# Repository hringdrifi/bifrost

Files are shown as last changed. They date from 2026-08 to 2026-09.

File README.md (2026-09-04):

# Bifrǫst

Bifrǫst is a split-keyboard design project by [hringdrifi](https://github.com/hringdrifi).

It is a wireless keyboard design based on the MDBT50Q module, which uses the Nordic nRF52840 SoC.

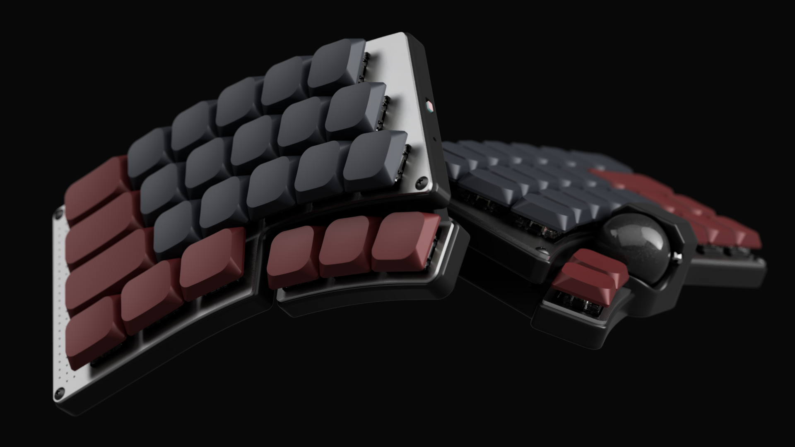
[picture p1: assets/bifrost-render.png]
Bifrǫst split keyboard render


## Project status

This keyboard is currently under active design. It is not yet a validated or production-ready design.

The case CAD files and PCB design files are published here. The keyboard firmware is maintained in the [zmk-config-bifrost repository](https://github.com/hringdrifi/zmk-config-bifrost).

## Available files

- [`case/`](case/README.md) — STEP files for the cases and switch plates
- [`pcb/`](pcb/) — KiCad sources for the five PCBs
- [`docs/manufacturing.md`](docs/manufacturing.md) — manufacturing reference ([日本語](docs/manufacturing.ja.md))
- [Firmware](https://github.com/hringdrifi/zmk-config-bifrost) — ZMK configuration and firmware source

## License

The design data in `case/` and `pcb/` is licensed under the [CERN Open Hardware Licence Version 2 - Permissive (CERN-OHL-P-2.0)](LICENSE).

This license permits use, modification, manufacture, and sale of the design data and products made from it. Modified design data does not need to be published, but applicable notices must be retained and modifications must be documented. The design data and any resulting products are provided without warranty.

The CERN-OHL-P-2.0 license applies to the contents of `case/` and `pcb/`. Firmware is licensed under the [MIT License](https://spdx.org/licenses/MIT.html).

## Disclaimer

Verify dimensions, clearances, compatibility, manufacturability, and safety for your own build before making any parts. Use of these files is at your own risk.

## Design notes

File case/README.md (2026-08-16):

# Bifrǫst case

3D CAD files for the Bifrǫst split-keyboard case. All files are in STEP (ISO 10303-214) format and can be viewed, modified, and manufactured with compatible CAD/CAM software.

## Files

| File | Description |
| --- | --- |
| `bifrost_left_case.step` | Left-hand case |
| `bifrost_right_case.step` | Right-hand case |
| `bifrost_trackball_case.step` | Trackball case |
| `bifrost_switch_knob.step` | Knob for the case-mounted power slide switch |
| `bifrost_left_plate.step` | Left-hand main switch plate |
| `bifrost_right_plate.step` | Right-hand main switch plate |
| `bifrost_left_thumb_plate.step` | Left-hand thumb-cluster switch plate |
| `bifrost_right_thumb_plate.step` | Right-hand thumb-cluster switch plate |

## Project status

These files are design work in progress. They have not been validated for manufacturing, fit, strength, safety, or compatibility with any particular PCB, component, or fabrication process.

Before manufacturing, verify the dimensions and clearances against the parts and process you intend to use.

## License

The STEP files in this directory are provided under the [CERN-OHL-P-2.0](../LICENSE). You may use, copy, modify, manufacture, and sell designs and products based on these files. They are provided without warranty.

See [NOTICE.md](NOTICE.md) for copyright and licensing notices.

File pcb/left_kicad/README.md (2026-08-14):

# Bifrǫst left KiCad design

KiCad source files for the left half of Bifrǫst.

## Status

This is an **incomplete and unverified work in progress**. Do not order boards or rely on this design without independently reviewing the schematic, layout, footprints, mechanical fit, and electrical connections.

The project was initially created from a Smiðr export, then received substantial additional modifications. It is no longer an unmodified Smiðr export.

## Contents

| Design | Purpose |
| --- | --- |
| `bifrost_left.kicad_pro` / `.kicad_sch` / `.kicad_pcb` | Left main PCB |
| `bifrost_left_plate.kicad_pro` / `.kicad_pcb` | Left main switch plate |
| `bifrost_left_thumb.kicad_pro` / `.kicad_sch` / `.kicad_pcb` | Left thumb-cluster PCB |
| `bifrost_left_thumb_plate.kicad_pro` / `.kicad_pcb` | Left thumb-cluster switch plate |
| `smidr.pretty/` | Project footprint library |
| `local.kicad_sym` | Project symbol library |

## Electrical design note

The switch design uses **direct GPIO connections**. Each switch is connected directly between its assigned GPIO net and GND; **there is no diode connected to each switch**.

## Libraries

`fp-lib-table` and `sym-lib-table` configure the project libraries. Keep `smidr.pretty/` and `local.kicad_sym` with this project when opening it in KiCad.

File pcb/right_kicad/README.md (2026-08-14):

# Bifrǫst right KiCad design

KiCad source files for the right half of Bifrǫst.

## Status

This is an **incomplete and unverified work in progress**. Do not order boards or rely on this design without independently reviewing the schematic, layout, footprints, mechanical fit, and electrical connections.

The project was initially created from a Smiðr export, then received substantial additional modifications. It is no longer an unmodified Smiðr export.

## Contents

| Design | Purpose |
| --- | --- |
| `bifrost_right.kicad_pro` / `.kicad_sch` / `.kicad_pcb` | Right main PCB |
| `bifrost_right_plate.kicad_pro` / `.kicad_pcb` | Right main switch plate |
| `bifrost_right_thumb.kicad_pro` / `.kicad_sch` / `.kicad_pcb` | Right thumb-cluster PCB |
| `bifrost_right_thumb_plate.kicad_pro` / `.kicad_pcb` | Right thumb-cluster switch plate |
| `bifrost_right_trackball.kicad_pro` / `.kicad_sch` / `.kicad_pcb` | Trackball PCB |
| `smidr.pretty/` | Project footprint library |
| `local.kicad_sym` | Project symbol library |

## Electrical design note

The switch design uses **direct GPIO connections**. Each switch is connected directly between its assigned GPIO net and GND; **there is no diode connected to each switch**.

## Libraries

`fp-lib-table` and `sym-lib-table` configure the project libraries. Keep `smidr.pretty/` and `local.kicad_sym` with this project when opening it in KiCad.

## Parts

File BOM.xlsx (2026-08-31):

left |  |  |  |  | right |  |  |  |  | leftthumb |  |  |  |  | rightthumb |  |  |  |  | righttrackball
Designator | Footprint | Quantity | Value | LCSC Part # | Designator | Footprint | Quantity | Value | LCSC Part # | Designator | Footprint | Quantity | Value | LCSC Part # | Designator | Footprint | Quantity | Value | LCSC Part # | Designator | Footprint | Quantity | Value | LCSC Part #
C1, C2, C3, C9 | 402 | 4 | 10u | C15525 | C1, C2, C3, C9 | 402 | 4 | 10u | C15525 | C1, C2 | 402 | 2 | 100n | C1525 | C1, C2, C3 | 402 | 3 | 100n | C1525 | C1, C3 | 402 | 2 | 10n | C15195
C4, C5 | 402 | 2 | 12pF | C1547 | C4, C5 | 402 | 2 | 12pF | C1547 | D1, D2 | 2020 | 2 | WS2812B-2020 | C55109522 | D1, D2, D3 | 2020 | 3 | WS2812B-2020 | C55109522 | C2, C5, C6 | 402 | 3 | 100n | C1525
C6, C8 | 402 | 2 | 100n | C1525 | C6, C8 | 402 | 2 | 100n | C1525 | H1, H2 |  | 2 | MountingHole | C2928170 | H1, H2 |  | 2 | MountingHole | C2928170 | C4 | 402 | 1 | 10u | C15525
C7 | 402 | 1 | 4.7u | C23733 | C7 | 402 | 1 | 4.7u | C23733 |  |  |  |  |  |  |  |  |  |  | C7 | 402 | 1 | 1u | C52923
CHG1 | 603 | 1 | Red | C19189741 | CHG1 | 603 | 1 | Red | C19189741 |  |  |  |  |  |  |  |  |  |  | C9 | 402 | 1 | 4.7uF/10V | C23733
D1 | D_SOD-323 | 1 | BSD3C051V | C151996 | D1 | D_SOD-323 | 1 | BSD3C051V | C151996 |  |  |  |  |  |  |  |  |  |  | R10 | 402 | 1 | 10k | C25744
D2 | D_SOD-323 | 1 | 1N5819WS | C191023 | D2 | D_SOD-323 | 1 | 1N5819WS | C191023 |  |  |  |  |  |  |  |  |  |  | U1 |  | 1 | PMW3610
D3 | LED_Smidr_RGB_1209 | 1 | E6C1209RGBC3UDA | C375572 |  |  |  |  |  |  |  |  |  |  |  |  |  |  |  | U2 |  | 1 | MCP1700T-1802E/TT | C150796
F1 | 1206 | 1 | PTC 1A hold | C883131 | F1 | 1206 | 1 | PTC 1A hold | C883131
J1 | USB_C_Receptacle_HRO_TYPE-C-31-M-12 | 1 | HRO_TYPE-C-31-M-12 | C165948 | J1 | USB_C_Receptacle_HRO_TYPE-C-31-M-12 | 1 | HRO_TYPE-C-31-M-12 | C165948
L1 | 603 | 1 | 10uH | C86083 | L1 | 603 | 1 | 10uH | C86083
L2, L3 | 402 | 2 | BLM15PX121SN1D | C88970 | L2, L3 | 402 | 2 | BLM15PX121SN1D | C88970
Q1, Q3 | SOT-23 | 2 | AO3401A | C15127 | Q1, Q3 | SOT-23 | 2 | AO3401A | C15127
Q2 | SOT-23 | 1 | 2N7002 | C8545 | Q2 | SOT-23 | 1 | 2N7002 | C8545
R1, R2 | 402 | 2 | 27 | C25100 | R1, R2 | 402 | 2 | 27 | C25100
R10, R11 | 402 | 2 | 4.7k | C25900
R12 | 402 | 1 | 1k | C11702
R13, R9 | 402 | 2 | 10k | C25744 | R10, R9 | 402 | 2 | 10k | C25744
R3 | 402 | 1 | 1.5k | C25867 | R3 | 402 | 1 | 1.5k | C25867
R4 | 402 | 1 | 100k | C25741 | R4 | 402 | 1 | 100k | C25741
R5, R6 | 402 | 2 | 5.1k | C25905 | R5, R6 | 402 | 2 | 5.1k | C25905
R7 | 402 | 1 | 3.3k | C25890 | R7 | 402 | 1 | 3.3k | C25890
R8 | 402 | 1 | 100 | C25076 | R8 | 402 | 1 | 100 | C25076
S1 | SW_SPDT_Shouhan_MSK12C02 | 1 | MSK12C02-HB | C431541 | S1 | SW_SPDT_Shouhan_MSK12C02 | 1 | MSK12C02-HB | C431541
T1 | SW_SMD_2P-TS24CA | 1 | TS24CA | C393942 | T1 | SW_SMD_2P-TS24CA | 1 | TS24CA | C393942
TP1 | TestPoint_THTPad_D1.0mm_Drill0.5mm | 1 | SWDIO |  | TP1 | TestPoint_THTPad_D1.0mm_Drill0.5mm | 1 | SWDIO
TP2 | TestPoint_THTPad_D1.0mm_Drill0.5mm | 1 | SWDCLK |  | TP2 | TestPoint_THTPad_D1.0mm_Drill0.5mm | 1 | SWDCLK
U1 | Raytac_MDBT50Q | 1 | MDBT50Q-1MV2 | C5118826 | U1 | Raytac_MDBT50Q | 1 | MDBT50Q-1MV2 | C5118826
U2 | SOT-23-6 | 1 | TP4057 | C12044 | U2 | SOT-23-6 | 1 | TP4057 | C12044
U3 | SOT-23-6 | 1 | SRV05-4 | C7420376 | U3 | SOT-23-6 | 1 | SRV05-4 | C7420376
X1 | Crystal_SMD_MicroCrystal_CC7V-T1A-2Pin_3.2x1.5mm | 1 | 32.768kHz | C32346 | X1 | Crystal_SMD_MicroCrystal_CC7V-T1A-2Pin_3.2x1.5mm | 1 | 32.768kHz | C32346

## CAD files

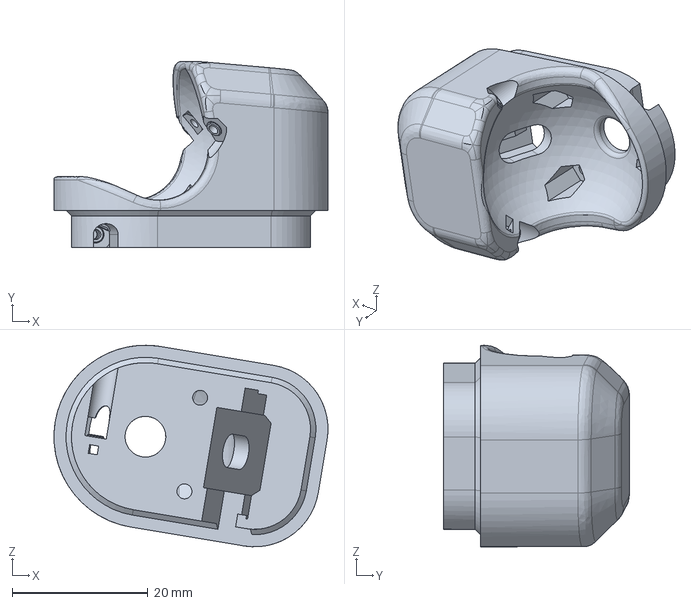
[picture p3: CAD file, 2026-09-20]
case/bifrost_trackball_case.step
40.4 x 27.5 x 29.7 mm

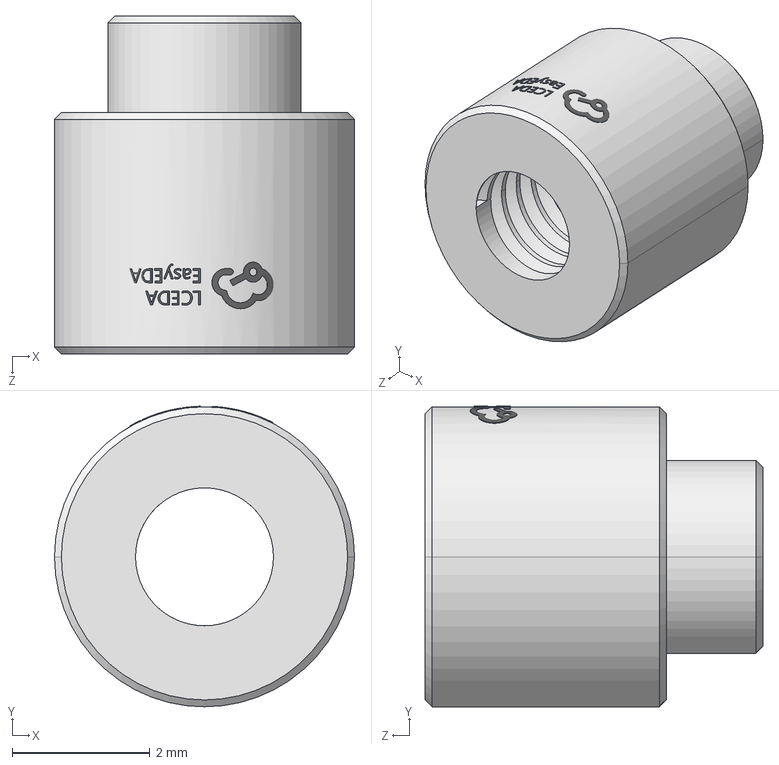
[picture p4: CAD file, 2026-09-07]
pcb/left_kicad/3dmodels/SMD-1_BD4.4-D2.8.step
4.35 x 4.36 x 4.90 mm

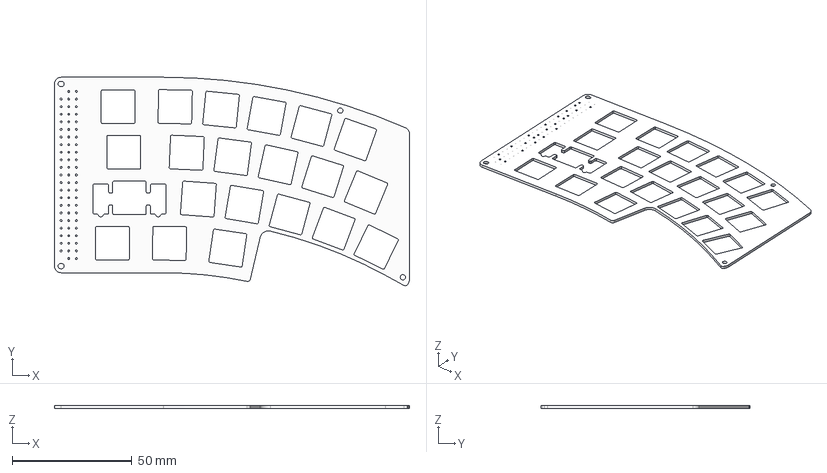
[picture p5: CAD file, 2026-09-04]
case/bifrost_left_plate.step
148.4 x 87.2 x 1.20 mm

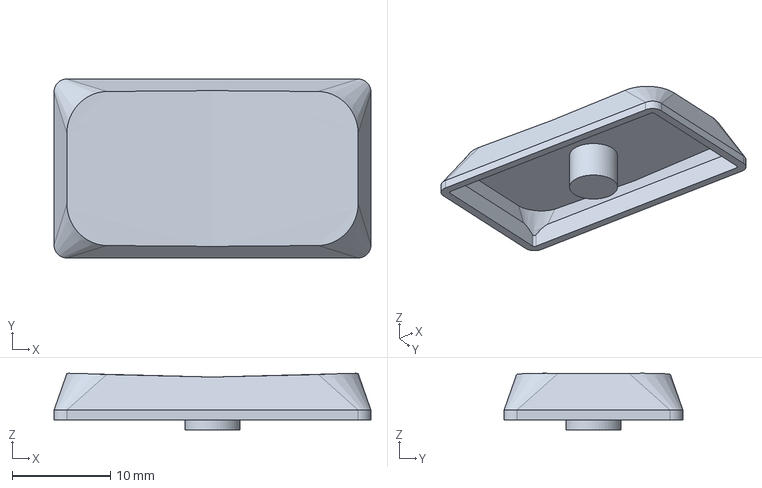
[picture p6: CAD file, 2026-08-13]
pcb/left_kicad/3dmodels/Low Profile Keycap 1.75U.step
32.3 x 18.2 x 5.76 mm

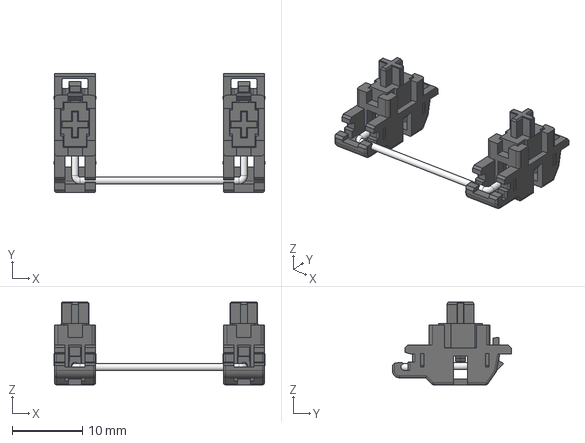
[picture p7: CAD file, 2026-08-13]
pcb/right_kicad/3dmodels/Gateron Low Profile Stabilizer 2U.step
30.0 x 17.0 x 11.8 mm

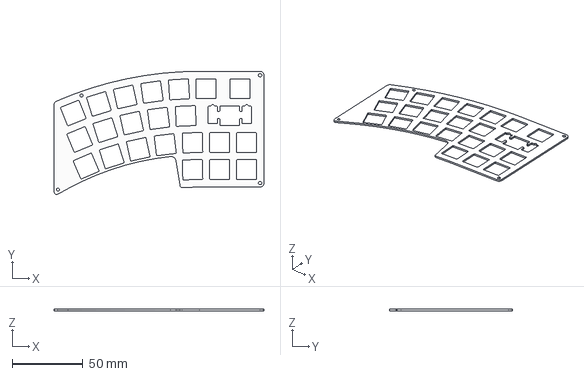
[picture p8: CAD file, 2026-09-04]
case/bifrost_right_plate.step
148.4 x 87.2 x 1.20 mm

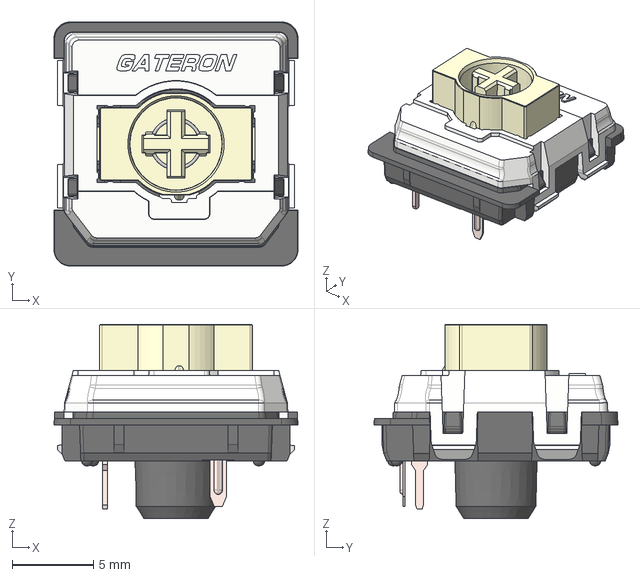
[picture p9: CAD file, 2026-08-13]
pcb/left_kicad/3dmodels/Gateron Low Profile Switch V2.step
15.0 x 15.0 x 11.9 mm

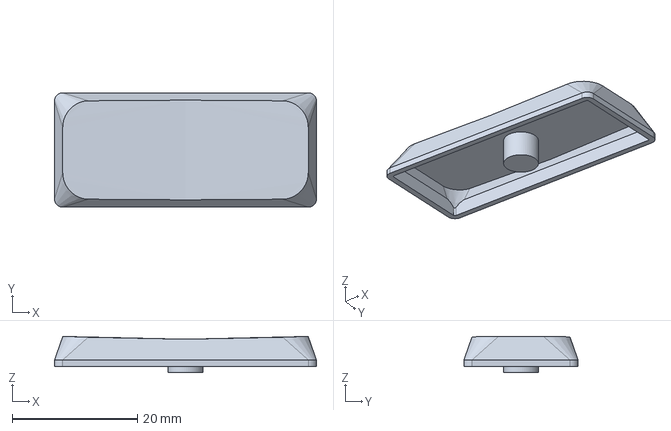
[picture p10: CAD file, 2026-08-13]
pcb/right_kicad/3dmodels/Low Profile Keycap 2.25U.step
41.8 x 18.2 x 5.76 mm

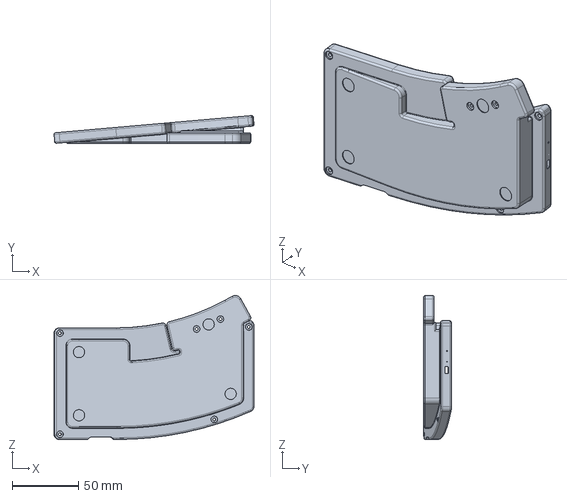
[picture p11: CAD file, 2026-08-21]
case/bifrost_left_case.step
150.7 x 21.0 x 108.6 mm

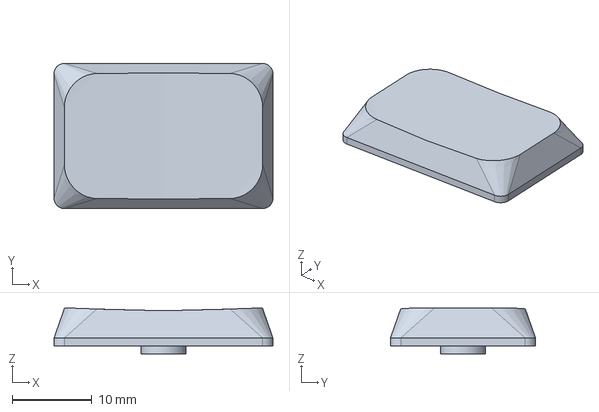
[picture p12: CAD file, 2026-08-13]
pcb/left_kicad/3dmodels/Low Profile Keycap 1.5U.step
27.5 x 18.2 x 5.75 mm

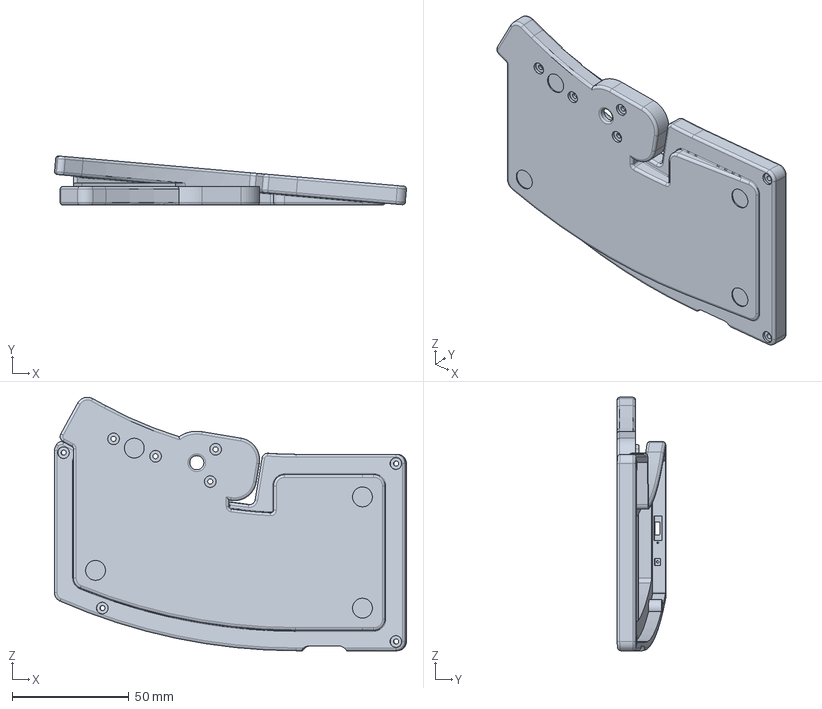
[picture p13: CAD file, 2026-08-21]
case/bifrost_right_case.step
150.7 x 21.0 x 108.6 mm

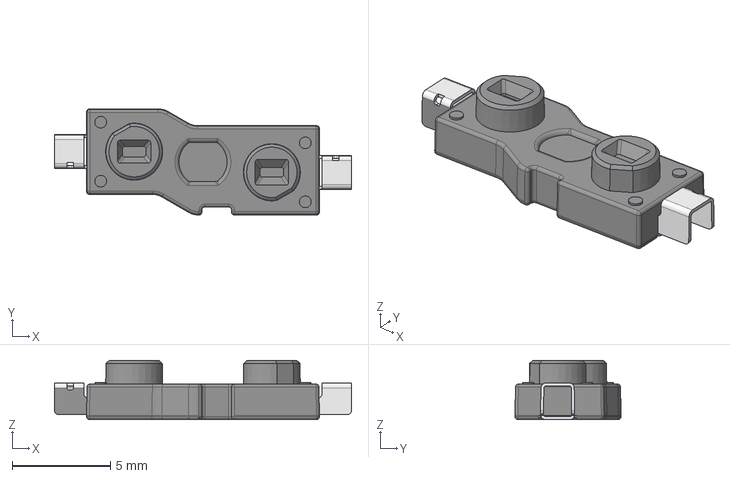
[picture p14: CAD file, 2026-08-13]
pcb/left_kicad/3dmodels/Gateron Low Profile Socket.step
15.1 x 5.39 x 3.00 mm

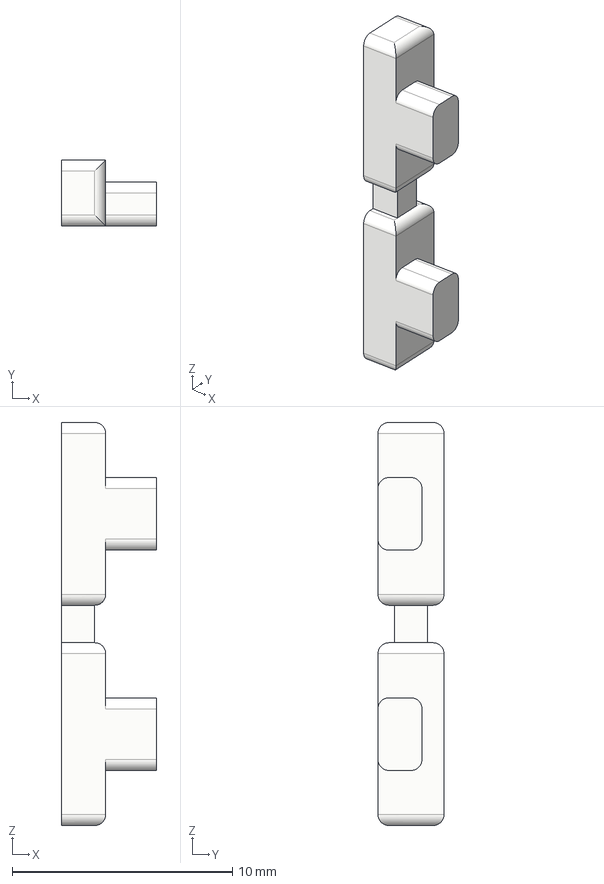
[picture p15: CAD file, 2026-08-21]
case/bifrost_switch_knob.step
4.30 x 3.00 x 18.3 mm

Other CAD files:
case/bifrost_left_thumb_plate.step
case/bifrost_right_thumb_plate.step
pcb/left_kicad/3dmodels/Low Profile Keycap 1.25U.step
pcb/left_kicad/3dmodels/Low Profile Keycap 1U.step
pcb/left_kicad/3dmodels/Low Profile Keycap 2U.step
pcb/right_kicad/3dmodels/Low Profile Keycap 1U.step

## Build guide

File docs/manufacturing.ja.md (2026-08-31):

# 製造資料

この文書は Bifrǫst を製造するための暫定資料です。調達・製造条件を扱い、はんだ付けや組み立て手順は別のビルドガイドで公開します。

> リンク先の在庫、納期、仕様、注文条件は変わる場合があります。注文前に必ず販売元の最新情報を確認してください。価格は掲載しません。

## 製造対象

キーボード 1 台あたり、次の 5 種類の基板を使用します。

1. 左右メイン基板（左）
2. 左右メイン基板（右）
3. トラックボール基板
4. 左親指クラスタ基板
5. 右親指クラスタ基板

ケースおよび 4 種類のプレートは [`case/`](../case/) に、基板設計データは [`pcb/`](../pcb/) にあります。

## 部品

| 部品 | 仕様 | 1 台あたり | 推奨購入先 | 型番 |
| --- | --- | ---: | --- | --- |
| トラスねじ | M2 × 4 mm | 22 本 | [Wilco](https://wilco.jp/) | `FT-0204EB` |
| ねじ | M1.4 × 5 mm | 3 本 | [Wilco](https://wilco.jp/) | `F-1450N-01` |
| アルミ製丸型両雌ねじスペーサー | M2 × 5 mm | 8 本 | [ヒロスギ](https://hirosugi.co.jp/)（[Web ショップ](https://www.hirosugi-net.co.jp/)） | `ARL-2005E` |
| ナット | M2 | 2 個 | [Wilco](https://wilco.jp/) | `FNT-02N` |
| 薄ナット | M1.4 | 3 個 | [Wilco](https://wilco.jp/) | `UNTD-014` |
| ゴム足 | φ7.9 × H2.2 mm | 8 個 | [Amazon](https://www.amazon.co.jp/) | `SJ5302` または `CS-01` |
| スイッチ | Gateron Low Profile ホットスワップ | 49 個 | TBD | `KS-27 Gateron Low Profile` または `KS-33 Gateron Low Profile 2.0` |
| スタビライザー | Gateron Low Profile、プレートマウント | 2 個 | TBD | `KS-57 Gateron Low Profile Plate Mounted Stabilizer` |
| トラックボール球 | 25 mm | 1 個 | TBD | — |
| トラックボール用ベアリング | 内径1.5 × 外径4 × 幅2 mm | 3 個 | TBD | ミネベア `DDL-415ZZ` |
| リチウムポリマー電池 | 1 セル（公称 3.7 V）、保護回路付き、最大寸法：厚み 6 × 幅 35 × 高さ 55 mm | 2 個 | TBD | TBD |
| メイン基板－バッテリー接続ワイヤハーネス | 2 芯、PicoBlade（1.25 mm ピッチ・2 ピン）オス／メスの 75 mm ピグテールを中間で接続 | 2 本 | Molex | `2181110200` + `2181120200` |
| 左メイン基板－左親指クラスタ基板接続ワイヤハーネス | 6 芯、PicoBlade（1.25 mm ピッチ・6 ピン）オス／メスの 75 mm ピグテールを中間で接続 | 1 本 | Molex | `2181110600` + `2181120600` |
| 右メイン基板－右親指クラスタ基板接続ワイヤハーネス | 5 芯、PicoBlade（1.25 mm ピッチ・5 ピン）オス／メスの 75 mm ピグテールを中間で接続 | 1 本 | Molex | `2181110500` + `2181120500` |
| 右メイン基板－トラックボール基板接続ワイヤハーネス | 6 芯、PicoBlade（1.25 mm ピッチ・6 ピン）オス／メスの 75 mm ピグテールを中間で接続 | 1 本 | Molex | `2181110600` + `2181120600` |

> アルミ製プレートに真鍮製のねじを直接接触させ、水分や塩分が介在すると、異種金属接触によってアルミ側の腐食が促進される場合があります。通常の乾燥した室内環境では大きな問題になりませんが、耐食性を優先する場合はステンレス製の締結部品を使用してください。

PicoBlade コネクタは基板上ではなく、各ハーネスの途中に着脱部として設けます。`218111` はオス－ピグテール、`218112` はメス－ピグテールのアセンブリ済みケーブルで、被覆むき線端を各基板へ接続します。各ハーネスは最短の 75 mm 品をオス・メス 1 本ずつ使用します。バッテリー用ハーネスは 2 ピンです。発注前にコネクタ形状、極数、ピン配列を現物および基板データで確認してください。

### リチウムポリマー電池に関する注意・免責

リチウムポリマー電池は、短絡、過充電、物理的な損傷、不適切な充電により発熱、発火、破裂するおそれがあります。本資料は電池、充電器、ハーネス、または完成品の安全性・適合性を保証するものではなく、組み立て、使用、充電、保管、廃棄は製作者・使用者の責任で行ってください。

- 充電は基板上の充電回路を介して行います。バッテリーまたはハーネスへ外部充電器を直接接続しないでください。保護回路付きの 1 セル電池を使用してください。
- 膨張、損傷、異臭、異常な発熱がある電池は使用・充電せず、電池メーカーおよび地域の廃棄ルールに従って処分してください。
- 可燃物の近く、就寝中、または監視できない状態で充電しないでください。極性と配線を確認してから接続してください。

## ケース製造

次の部品を **SLA レジン 3D プリント**で製造します。

| 部品 | ファイル | 1 台あたり |
| --- | --- | ---: |
| 左ケース | `bifrost_left_case.step` | 1 個 |
| 右ケース | `bifrost_right_case.step` | 1 個 |
| トラックボールケース | `bifrost_trackball_case.step` | 1 個 |
| 電源スイッチ用ノブ（2 個一体モデル） | `bifrost_switch_knob.step` | 1 モデル（ノブ 2 個） |

電源スイッチ用ノブは単体では小さすぎて製造できないため、2 個をつないだ 1 つの 3D モデルとして出力します。出力後に 2 個のノブを切り離してください。

- 推奨製造先: [JLC3DP](https://jlc3dp.com/)
- 製法: SLA レジン
- レジンの種類・色・表面仕上げ: **製作者が任意に選択**
- 後加工: **不要**
- ゴム足: 最終組み立て時に 3M `SJ5302` を 8 個取り付けます。

## PCB 製造

- 推奨製造先: [JLCPCB](https://jlcpcb.com/)
- 1 台あたり: **5 種類の基板**

| 基板 | 基板厚 |
| --- | ---: |
| 左メイン基板 | **1.2 mm** |
| 右メイン基板 | **1.2 mm** |
| 左親指クラスタ基板 | **1.2 mm** |
| 右親指クラスタ基板 | **1.2 mm** |
| トラックボール基板 | **1.6 mm** |

### 注文条件 — 未確定

注文前に以下を確定します。

| 項目 | 条件 |
| --- | --- |
| 基板ごとの注文数 | TBD |
| 層数 | 2 層 |
| 銅箔厚 | 1 oz（35 µm）— トラックボール基板は要確認 |
| レジスト色 | 製造者が任意に選択 |
| 表面処理 | TBD |
| 外形・面付け条件 | TBD |
| 電気検査 | TBD |
| 実装サービス | TBD |
| 製造ファイル | 左右メイン基板は下表のGerber ZIP、BOM、部品位置ファイルを使用 |

### 左右メイン基板の製造・実装データ

左メイン基板と右メイン基板は、それぞれ1枚ずつで1台分です。JLCPCB実装では各基板ごとに、Gerber ZIP、BOM CSV、部品位置CSVを同じ組み合わせでアップロードしてください。BOMの `LCSC Part #` はJLCPCB/LCSCの部品番号です。

| 基板 | Gerber ZIP | BOM | 部品位置 |
| --- | --- | --- | --- |
| 左メイン基板 | [`bifrost_left.zip`](../pcb/left_kicad/production/bifrost_left.zip) | [`bom.csv`](../pcb/left_kicad/production/bom.csv) | [`positions.csv`](../pcb/left_kicad/production/positions.csv) |
| 右メイン基板 | [`bifrost_right.zip`](../pcb/right_kicad/production/bifrost_right.zip) | [`bom.csv`](../pcb/right_kicad/production/bom.csv) | [`positions.csv`](../pcb/right_kicad/production/positions.csv) |

現在のBOMにおける要確認部品は次のとおりです。

| 部品 | 指定部品 | JLCPCB/LCSC Part # | 備考 |
| --- | --- | --- | --- |
| J1 | Korean Hroparts `TYPE-C-31-M-12` | `C165948` | 基板の `HRO_TYPE-C-31-M-12` フットプリントに対応するUSB Type-Cレセプタクル |
| L1 | Murata `LQM18FN100M00D` | `C86083` | 10 µH、0603。nRF52840のDC/DC用 |
| F1 | BHFUSE `BSMD1206-100-16V` | `C883131` | 1 A hold PTC |
| D2 | Guangdong Hottech `1N5819WS` | `C191023` | SOD-323ショットキーダイオード |

この表にない実装部品も、必ず上記のBOM CSVに記載された部品番号を使用してください。スイッチ、バッテリー、ハーネスなど、BOM CSVに含まれない部品は別途調達・組み立てします。

## プレート製造

4 種類のスイッチプレートはレーザーカット、またはアルミ基板で製造できます。厚みは **1.2 mm** です。

アルミ基板を使い、アルミ面を上面にする場合は、**プレートのデータを表裏反転して発注**してください。

- 推奨製造先: [JLCPCB](https://jlcpcb.com/)
- 対象ファイル: `bifrost_left_plate.step`、`bifrost_right_plate.step`、`bifrost_left_thumb_plate.step`、`bifrost_right_thumb_plate.step`

## 今後追記する内容

- PCB の詳細な注文条件
- 親指クラスタ・トラックボール基板の実装データと部品購入リンク
- 製造データのリビジョン番号

## 関連資料

- [English version](manufacturing.md)
- はんだ付け、機械組み立て、ファームウェア書き込みは別のビルドガイドで扱います。

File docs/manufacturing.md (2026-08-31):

# Manufacturing reference

This document is a work in progress for manufacturing Bifrǫst. It covers procurement and fabrication requirements; assembly instructions will be published separately in a build guide.

> Availability, lead time, specifications, and ordering conditions at linked suppliers may change. Verify the current product page and specification before ordering. Prices are intentionally not listed here.

## Production scope

One keyboard requires five PCB designs:

1. Left main PCB
2. Right main PCB
3. Trackball PCB
4. Left thumb-cluster PCB
5. Right thumb-cluster PCB

The case and four switch plates are provided as STEP files in [`case/`](../case/). The PCB design sources are in [`pcb/`](../pcb/).

## Parts

| Part | Specification | Qty. per keyboard | Recommended supplier | Part number |
| --- | --- | ---: | --- | --- |
| Truss-head screw | M2 × 4 mm | 22 | [Wilco](https://wilco.jp/) | `FT-0204EB` |
| Screw | M1.4 × 5 mm | 3 | [Wilco](https://wilco.jp/) | `F-1450N-01` |
| Aluminium round female-to-female spacer | M2 × 5 mm | 8 | [Hirosugi](https://hirosugi.co.jp/) ([web shop](https://www.hirosugi-net.co.jp/)) | `ARL-2005E` |
| Nut | M2 | 2 | [Wilco](https://wilco.jp/) | `FNT-02N` |
| Thin nut | M1.4 | 3 | [Wilco](https://wilco.jp/) | `UNTD-014` |
| Bumpon / rubber foot | Ø7.9 × H2.2 mm | 8 | [Amazon](https://www.amazon.co.jp/) | `SJ5302` or `CS-01` |
| Switch | Gateron Low Profile hotswap | 49 | TBD | `KS-27 Gateron Low Profile` or `KS-33 Gateron Low Profile 2.0` |
| Stabilizer | Gateron Low Profile, plate-mounted | 2 | TBD | `KS-57 Gateron Low Profile Plate Mounted Stabilizer` |
| Trackball ball | 25 mm | 1 | TBD | — |
| Trackball bearing | ID1.5 × OD4 × W2 mm | 3 | TBD | Minebea `DDL-415ZZ` |
| Lithium-polymer battery | Single cell (3.7 V nominal), with protection circuit; maximum dimensions: 6 mm thick × 35 mm wide × 55 mm high | 2 | TBD | TBD |
| Main PCB–battery wire harness | Two-conductor; inline connection between 75 mm male and female PicoBlade (1.25 mm pitch, 2 pin) pigtails | 2 | Molex | `2181110200` + `2181120200` |
| Left main PCB–left thumb-cluster PCB wire harness | Six-conductor; inline connection between 75 mm male and female PicoBlade (1.25 mm pitch, 6 pin) pigtails | 1 | Molex | `2181110600` + `2181120600` |
| Right main PCB–right thumb-cluster PCB wire harness | Five-conductor; inline connection between 75 mm male and female PicoBlade (1.25 mm pitch, 5 pin) pigtails | 1 | Molex | `2181110500` + `2181120500` |
| Right main PCB–trackball PCB wire harness | Six-conductor; inline connection between 75 mm male and female PicoBlade (1.25 mm pitch, 6 pin) pigtails | 1 | Molex | `2181110600` + `2181120600` |

> Direct contact between aluminium plates and brass screws can accelerate corrosion of the aluminium if moisture or salt is present. This is not normally significant in a dry indoor environment, but use stainless-steel fasteners where corrosion resistance is a priority.

Place the PicoBlade connector in each harness as an inline disconnect, not on either PCB. `218111` is a male-to-pigtail and `218112` a female-to-pigtail pre-assembled cable; connect their blunt wire ends to the respective PCBs. Each harness uses one 75 mm male and one 75 mm female pigtail, the shortest available length. The battery harnesses use 2-pin connectors. Confirm connector mating, pin count, and pinout against the actual parts and PCB design data before ordering.

### Lithium-polymer battery notice and disclaimer

Lithium-polymer batteries can overheat, catch fire, or rupture if short-circuited, overcharged, physically damaged, or improperly charged. This reference does not warrant the safety or compatibility of any battery, charger, harness, or completed product; builders and users are responsible for assembly, use, charging, storage, and disposal.

- Charge through the on-board charging circuit. Do not connect an external charger directly to the battery or harness; use protected single-cell batteries.
- Do not use or charge batteries that are swollen, damaged, unusually hot, or emitting an odour. Dispose of them according to the battery manufacturer's instructions and local rules.
- Do not charge near combustible materials, while asleep, or while the battery cannot be supervised. Verify polarity and wiring before connecting.

## Case fabrication

Manufacture the following parts by **SLA resin 3D printing**:

| Part | File | Qty. per keyboard |
| --- | --- | ---: |
| Left-hand case | `bifrost_left_case.step` | 1 |
| Right-hand case | `bifrost_right_case.step` | 1 |
| Trackball case | `bifrost_trackball_case.step` | 1 |
| Power-switch knob (two-knob joined model) | `bifrost_switch_knob.step` | 1 model (2 knobs) |

The power-switch knobs are too small to manufacture individually, so the STEP file contains two knobs joined as one 3D-printing model. Separate the two knobs after printing.

- Recommended manufacturer: [JLC3DP](https://jlc3dp.com/)
- Manufacturing process: SLA resin
- Resin type, colour, and surface finish: **at the builder's discretion**
- Post-processing: **not required**
- Rubber feet: apply eight 3M `SJ5302` bump-ons during final assembly.

## PCB fabrication

- Recommended manufacturer: [JLCPCB](https://jlcpcb.com/)
- Required design count: **5 distinct PCBs** per keyboard

| PCB | Board thickness |
| --- | ---: |
| Left main PCB | **1.2 mm** |
| Right main PCB | **1.2 mm** |
| Left thumb-cluster PCB | **1.2 mm** |
| Right thumb-cluster PCB | **1.2 mm** |
| Trackball PCB | **1.6 mm** |

### Order specification — to be confirmed

Fill in the following before placing an order:

| Item | Requirement |
| --- | --- |
| Quantity per design | TBD |
| Layer count | 2 |
| Copper weight | 1 oz (35 µm) — verify for the trackball PCB |
| Solder mask colour | Builder's choice |
| Surface finish | TBD |
| Edge / panel requirements | TBD |
| Electrical test | TBD |
| Assembly service | TBD |
| Manufacturing files | Use the Gerber ZIP, BOM, and pick-and-place files in the table below for the main PCBs |

### Main-PCB fabrication and assembly data

One keyboard requires one left main PCB and one right main PCB. For JLCPCB assembly, upload the matching Gerber ZIP, BOM CSV, and pick-and-place CSV for each PCB. `LCSC Part #` in the BOM is the JLCPCB/LCSC component number.

| PCB | Gerber ZIP | BOM | Pick-and-place |
| --- | --- | --- | --- |
| Left main PCB | [`bifrost_left.zip`](../pcb/left_kicad/production/bifrost_left.zip) | [`bom.csv`](../pcb/left_kicad/production/bom.csv) | [`positions.csv`](../pcb/left_kicad/production/positions.csv) |
| Right main PCB | [`bifrost_right.zip`](../pcb/right_kicad/production/bifrost_right.zip) | [`bom.csv`](../pcb/right_kicad/production/bom.csv) | [`positions.csv`](../pcb/right_kicad/production/positions.csv) |

The following application-specific selections in the current BOM deserve particular attention:

| Reference | Selected part | JLCPCB/LCSC Part # | Note |
| --- | --- | --- | --- |
| J1 | Korean Hroparts `TYPE-C-31-M-12` | `C165948` | USB Type-C receptacle matching the board's `HRO_TYPE-C-31-M-12` footprint |
| L1 | Murata `LQM18FN100M00D` | `C86083` | 10 µH, 0603; nRF52840 DC/DC inductor |
| F1 | BHFUSE `BSMD1206-100-16V` | `C883131` | 1 A hold PTC |
| D2 | Guangdong Hottech `1N5819WS` | `C191023` | SOD-323 Schottky diode |

For all other assembled components, use the exact part number in the linked BOM CSV. Switches, batteries, harnesses, and other items absent from the CSV are sourced and assembled separately.

## Switch plates

The four switch plates may be made by laser cutting or as aluminium-core PCBs. Use **1.2 mm** material.

When ordering an aluminium-core PCB and using the aluminium face as the top surface, **mirror the plate artwork before fabrication**.

- Recommended manufacturer: [JLCPCB](https://jlcpcb.com/)
- Plate files: `bifrost_left_plate.step`, `bifrost_right_plate.step`, `bifrost_left_thumb_plate.step`, and `bifrost_right_thumb_plate.step`

## Still to be specified

- PCB order specifications listed above
- Assembly data and component sourcing links for the thumb-cluster and trackball PCBs
- Manufacturing-export revision identifiers

## Related documents

- [Japanese version](manufacturing.ja.md)
- A separate build guide will cover soldering, mechanical assembly, and firmware flashing.

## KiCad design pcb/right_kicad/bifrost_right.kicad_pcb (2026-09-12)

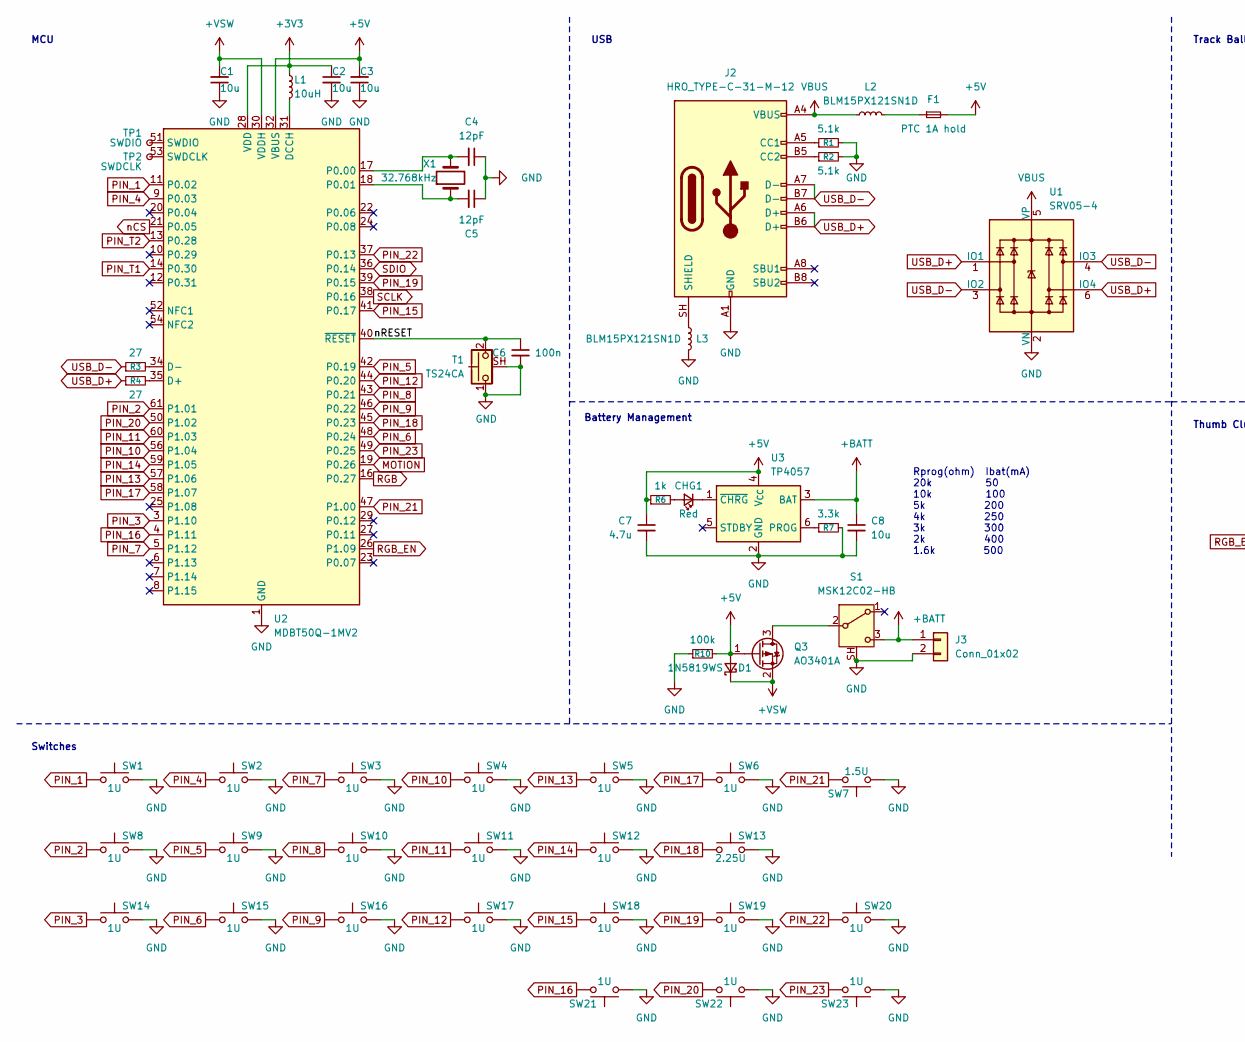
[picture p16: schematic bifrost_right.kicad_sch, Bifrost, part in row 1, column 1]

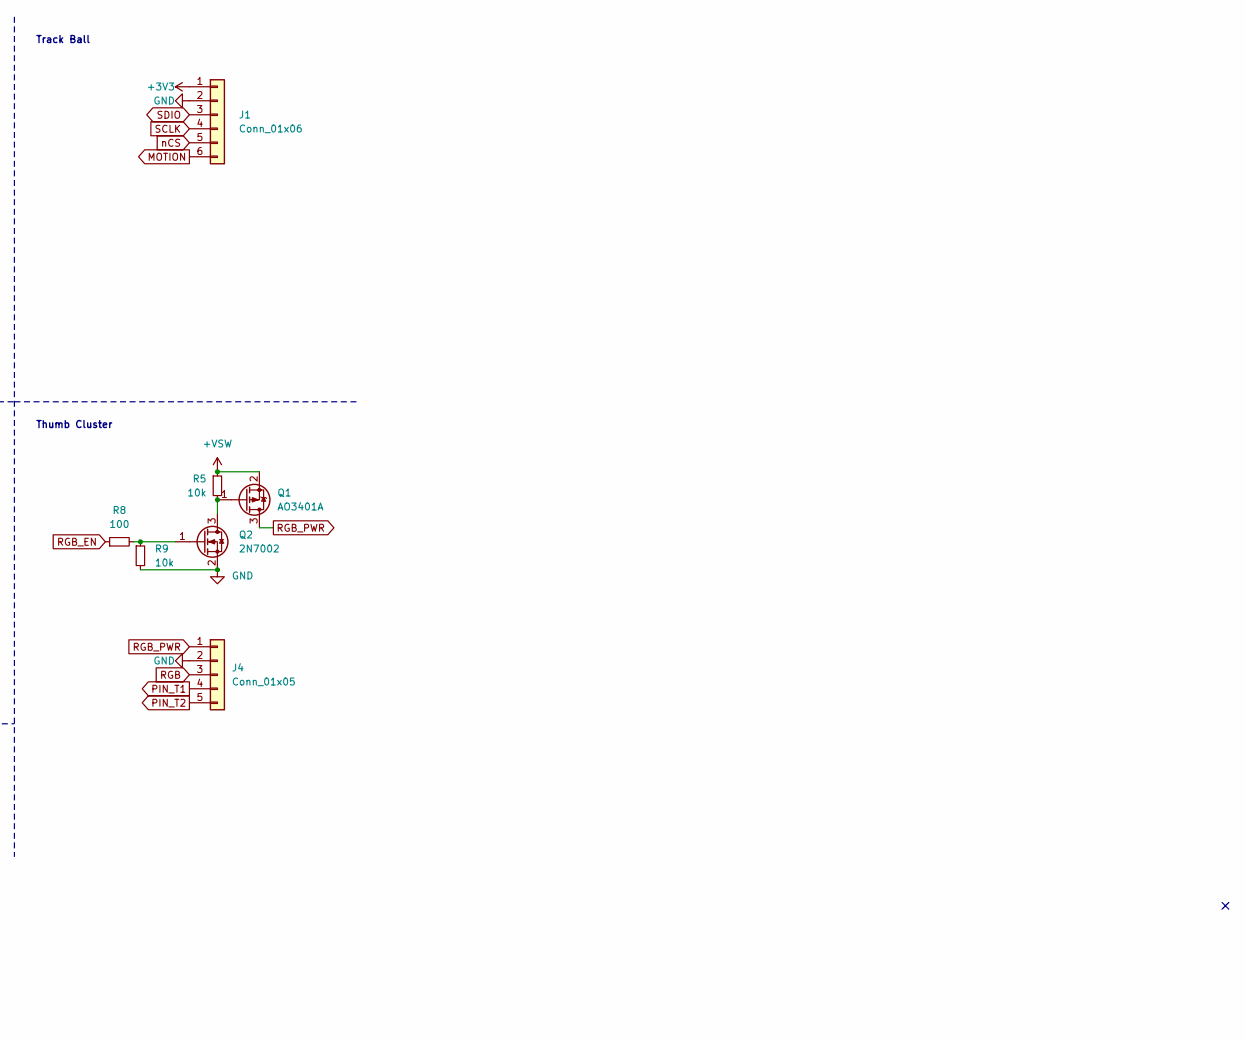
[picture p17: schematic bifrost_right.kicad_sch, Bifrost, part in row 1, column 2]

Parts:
C1, C2, C3, C8: 10u; C_0402_1005Metric; JLCPCB Part # C15525
C4, C5: 12pF; C_0402_1005Metric; JLCPCB Part # C1547
C6: 100n; C_0402_1005Metric; JLCPCB Part # C1525
C7: 4.7u; C_0402_1005Metric; JLCPCB Part # C23733
CHG1: Red; LED_0603_1608Metric; JLCPCB Part # C19189741
D1: 1N5819WS; D_SOD-323; JLCPCB Part # C191023
F1: PTC 1A hold; Fuse_1206_3216Metric; JLCPCB Part # C883131
J1: Conn_01x06; PinHeader_1x06_P1.27mm_Vertical
J2: HRO_TYPE-C-31-M-12; USB_C_Receptacle_HRO_TYPE-C-31-M-12; JLCPCB Part # C165948
J3: Conn_01x02; PinHeader_1x02_P1.27mm_Vertical
J4: Conn_01x05; PinHeader_1x05_P1.27mm_Vertical
L1: 10uH; L_0603_1608Metric; JLCPCB Part # C86083
L2, L3: BLM15PX121SN1D; L_0402_1005Metric; JLCPCB Part # C88970
Q1, Q3: AO3401A; SOT-23; JLCPCB Part # C15127
Q2: 2N7002; SOT-23; JLCPCB Part # C8545
R1, R2: 5.1k; R_0402_1005Metric; JLCPCB Part # C25905
R3, R4: 27; R_0402_1005Metric; JLCPCB Part # C25100
R5, R9: 10k; R_0402_1005Metric; JLCPCB Part # C25744
R6: 1k; R_0402_1005Metric; JLCPCB Part # C11702
R7: 3.3k; R_0402_1005Metric; JLCPCB Part # C25890
R8: 100; R_0402_1005Metric; JLCPCB Part # C25076
R10: 100k; R_0402_1005Metric; JLCPCB Part # C25741
S1: MSK12C02-HB; SW_SPDT_Shouhan_MSK12C02; JLCPCB Part # C431541
SW1, SW2, SW3, SW4, SW5, SW6, SW8, SW9, SW10, SW11, SW12, SW14, SW15, SW16, SW17, SW18, SW19, SW20, SW21, SW22, SW23: 1U; SW_Smidr_Gateron_LP_Hotswap
SW7: 1.5U; SW_Smidr_Gateron_LP_Hotswap
SW13: 2.25U; SW_Smidr_Gateron_LP_Hotswap
T1: TS24CA; SW_SMD_2P-TS24CA; JLCPCB Part # C393942
TP1: SWDIO; TestPoint_THTPad_D1.0mm_Drill0.5mm
TP2: SWDCLK; TestPoint_THTPad_D1.0mm_Drill0.5mm
U1: SRV05-4; SOT-23-6; JLCPCB Part # C7420376
U2: MDBT50Q-1MV2; Raytac_MDBT50Q; JLCPCB Part # C5118826
U3: TP4057; SOT-23-6; JLCPCB Part # C12044
X1: 32.768kHz; Crystal_SMD_MicroCrystal_CC7V-T1A-2Pin_3.2x1.5mm; JLCPCB Part # C479190

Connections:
+3V3: C2.1, J1.1, L1.1, U2.28 (VDD)
+5V: C3.2, C7.1, D1.2 (A), F1.2, Q3.1 (G), R6.1, R10.2, U2.32 (VBUS), U3.4 (V_{CC})
+BATT: C8.1, J3.1, S1.3 (C), U3.3 (BAT)
+VSW: C1.2, D1.1 (K), Q1.2 (S), Q3.2 (S), R5.1, U2.30 (VDDH)
/nRESET: C6.1, T1.2, U2.40 (~RESET)
GND: C1.1, C2.2, C3.1, C4.1, C5.1, C6.2, C7.2, C8.2, J1.2, J2.A1 (GND), J2.A12 (GND), J2.B1 (GND), J2.B12 (GND), J3.2, J4.2, L3.2, Q2.2 (S), R1.2, R2.2, R7.2, R9.2, R10.1, S1.SH, SW1.2, SW2.2, SW3.2, SW4.2, SW5.2, SW6.2, SW7.1, SW8.2, SW9.2, SW10.2, SW11.2, SW12.2, SW13.2, SW14.2, SW15.2, SW16.2, SW17.2, SW18.2, SW19.2, SW20.2, SW21.1, SW22.1, SW23.1, T1.1, T1.SH (B), U1.2 (VN), U2.1 (GND), U2.2 (GND), U2.15 (GND), U2.33 (GND), U2.55 (GND), U3.2 (GND)
MOTION: J1.6, U2.19 (P0.26)
unnamed: CHG1.2 (A), R6.2
unnamed: CHG1.1 (K), U3.1 (~CHRG)
unnamed: F1.1, L2.2
unnamed: J2.A5 (CC1), R1.1
unnamed: J2.B5 (CC2), R2.1
unnamed: J2.SH (SHIELD), L3.1
unnamed: Q1.1 (G), Q2.3 (D), R5.2
unnamed: Q2.1 (G), R8.2, R9.1
unnamed: Q3.3 (D), S1.2 (B)
unnamed: R4.2, U2.35 (D+)
unnamed: R3.2, U2.34 (D-)
unnamed: L1.2, U2.31 (DCCH)
unnamed: C4.2, U2.17 (P0.00), X1.2
unnamed: C5.2, U2.18 (P0.01), X1.1
unnamed: TP2.1 (1_1), U2.53 (SWDCLK)
unnamed: TP1.1 (1_1), U2.51 (SWDIO)
unnamed: R7.1, U3.6 (PROG)
PIN_1: SW1.1, U2.11 (P0.02)
PIN_2: SW8.1, U2.61 (P1.01)
PIN_3: SW14.1, U2.3 (P1.10)
PIN_4: SW2.1, U2.9 (P0.03)
PIN_5: SW9.1, U2.42 (P0.19)
PIN_6: SW15.1, U2.48 (P0.24)
PIN_7: SW3.1, U2.5 (P1.12)
PIN_8: SW10.1, U2.43 (P0.21)
PIN_9: SW16.1, U2.46 (P0.22)
PIN_10: SW4.1, U2.56 (P1.04)
PIN_11: SW11.1, U2.60 (P1.03)
PIN_12: SW17.1, U2.44 (P0.20)
PIN_13: SW5.1, U2.57 (P1.06)
PIN_14: SW12.1, U2.59 (P1.05)
PIN_15: SW18.1, U2.41 (P0.17)
PIN_16: SW21.2, U2.4 (P1.11)
PIN_17: SW6.1, U2.58 (P1.07)
PIN_18: SW13.1, U2.45 (P0.23)
PIN_19: SW19.1, U2.39 (P0.15)
PIN_20: SW22.2, U2.50 (P1.02)
PIN_21: SW7.2, U2.47 (P1.00)
PIN_22: SW20.1, U2.37 (P0.13)
PIN_23: SW23.2, U2.49 (P0.25)
PIN_T1: J4.4, U2.14 (P0.30)
PIN_T2: J4.5, U2.13 (P0.28)
RGB: J4.3, U2.16 (P0.27)
RGB_EN: R8.1, U2.26 (P1.09)
RGB_PWR: J4.1, Q1.3 (D)
SCLK: J1.4, U2.38 (P0.16)
SDIO: J1.3, U2.36 (P0.14)
USB_D+: J2.A6 (D+), J2.B6 (D+), R4.1, U1.1 (IO1), U1.6 (IO4)
USB_D-: J2.A7 (D-), J2.B7 (D-), R3.1, U1.3 (IO2), U1.4 (IO3)
VBUS: J2.A4 (VBUS), J2.A9 (VBUS), J2.B4 (VBUS), J2.B9 (VBUS), L2.1, U1.5 (VP)
nCS: J1.5, U2.21 (P0.05)

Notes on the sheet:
Thumb Cluster
MCU
Battery Management
Track Ball
USB
Rprog(ohm) Ibat(mA) 20k 50 10k 100 5k 200 4k 250 3k 300 2k 400 1.6k 500
Switches

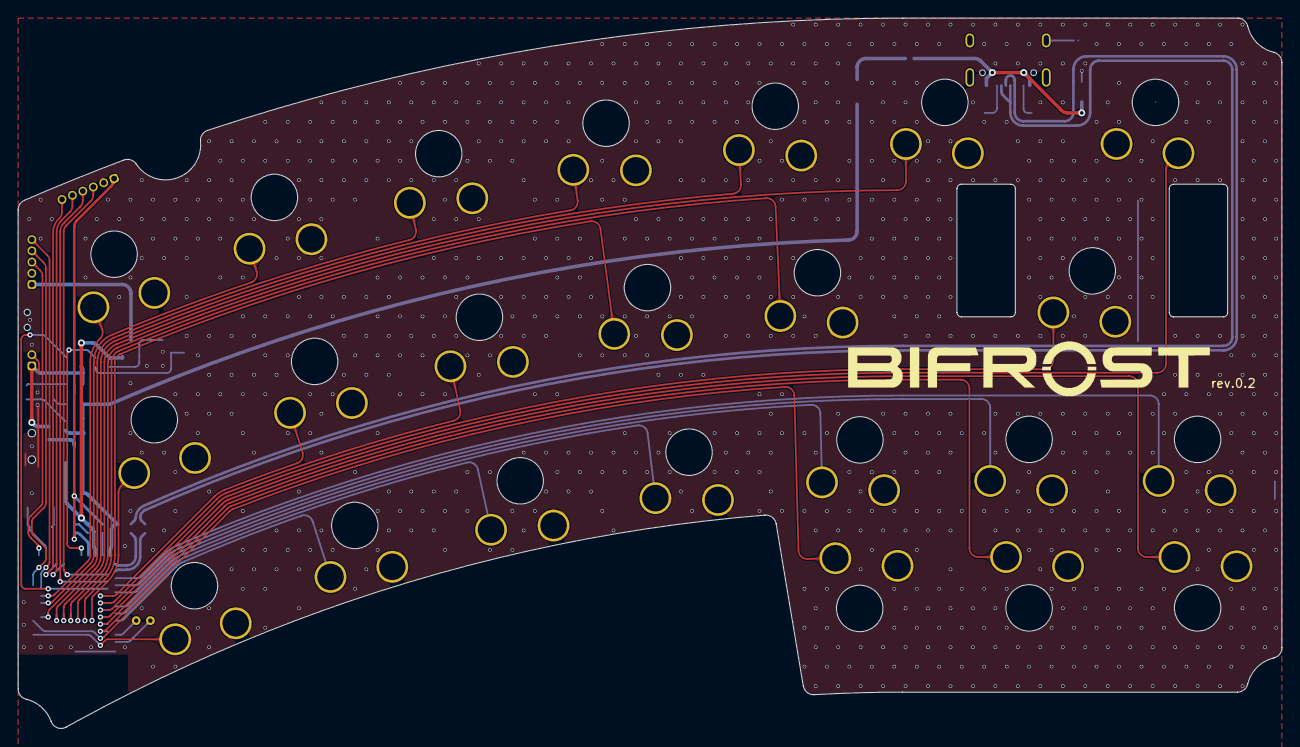
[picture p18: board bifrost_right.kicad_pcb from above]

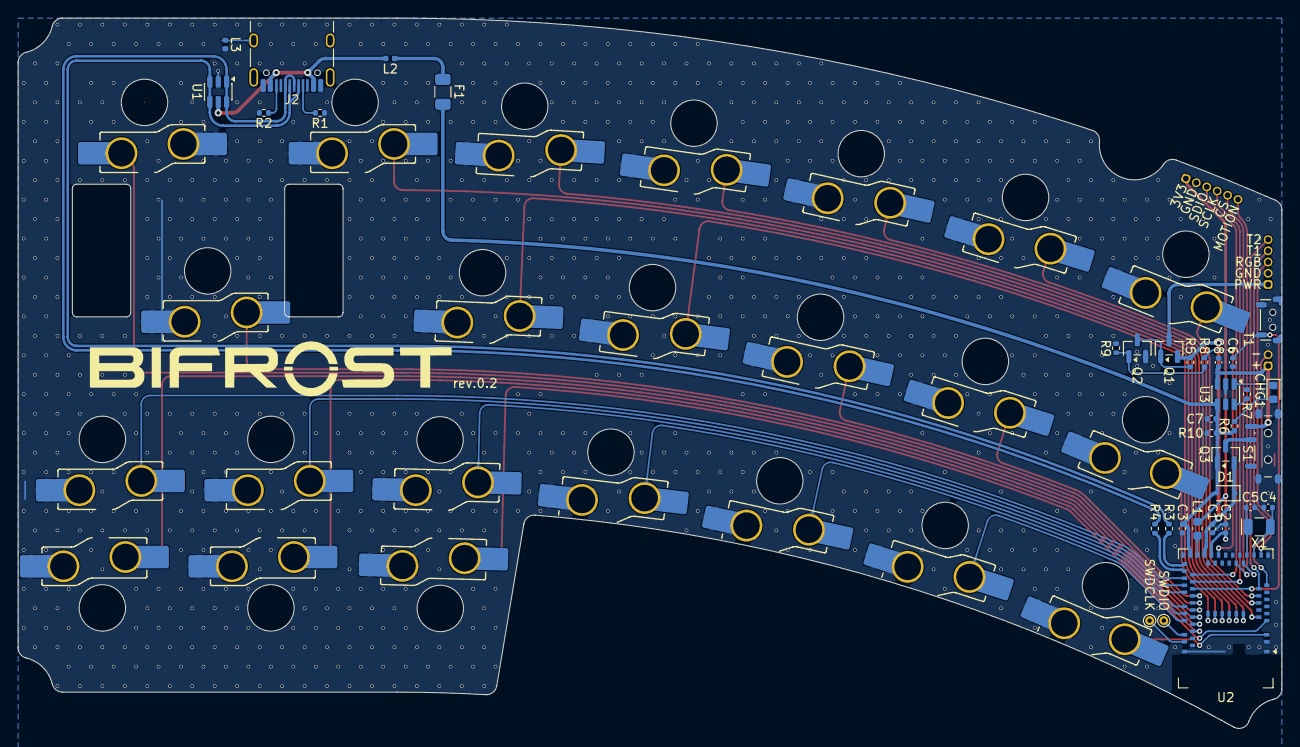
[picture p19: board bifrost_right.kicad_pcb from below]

Board: 2 copper layers, 142.9 x 80.3 mm, 62 parts (62 on the bottom side), 58 nets.

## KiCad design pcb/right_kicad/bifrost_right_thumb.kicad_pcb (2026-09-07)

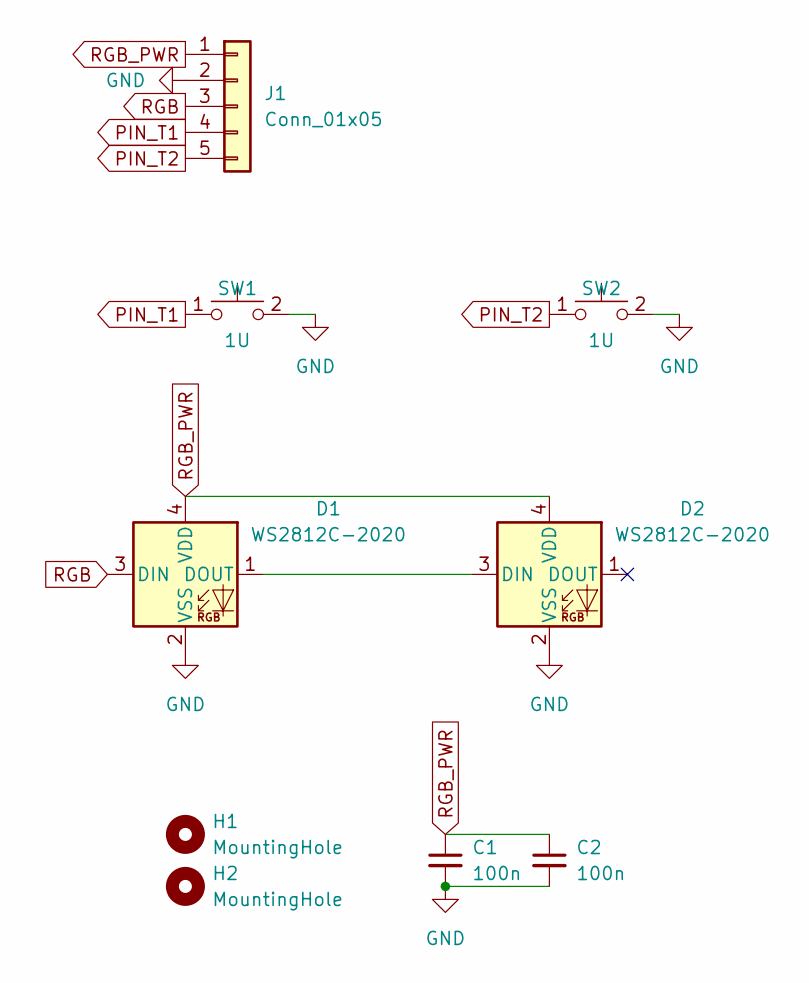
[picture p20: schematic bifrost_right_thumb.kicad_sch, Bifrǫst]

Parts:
C1, C2: 100n; C_0402_1005Metric; JLCPCB Part # C1525
D1, D2: WS2812C-2020; LED_WS2812B-2020_PLCC4_2.0x2.0mm; JLCPCB Part # C55109522
H1, H2: MountingHole; SMD-1_BD4.4-D2.8; JLCPCB Part # C2928179
J1: Conn_01x05; PinHeader_1x05_P1.27mm_Vertical
SW1, SW2: 1U; SW_Smidr_Gateron_LP_Hotswap

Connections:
GND: C1.2, C2.2, D1.2 (VSS), D2.2 (VSS), J1.2, SW1.2, SW2.2
unnamed: D1.1 (DOUT), D2.3 (DIN)
PIN_T1: J1.4, SW1.1
PIN_T2: J1.5, SW2.1
RGB: D1.3 (DIN), J1.3
RGB_PWR: C1.1, C2.1, D1.4 (VDD), D2.4 (VDD), J1.1

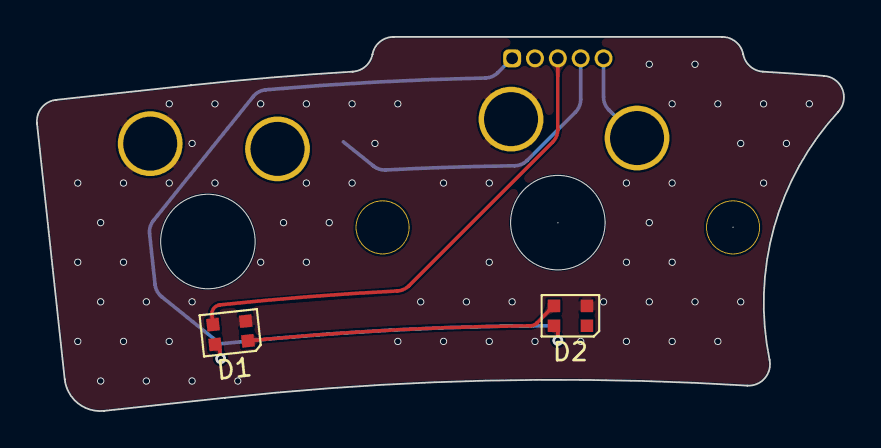
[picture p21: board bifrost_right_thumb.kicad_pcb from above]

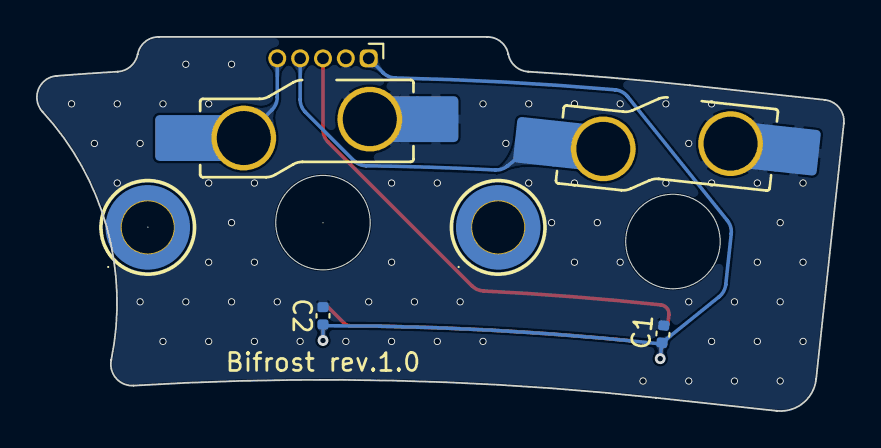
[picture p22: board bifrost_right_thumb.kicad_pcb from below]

Board: 2 copper layers, 44.8 x 20.8 mm, 9 parts (7 on the bottom side), 6 nets.

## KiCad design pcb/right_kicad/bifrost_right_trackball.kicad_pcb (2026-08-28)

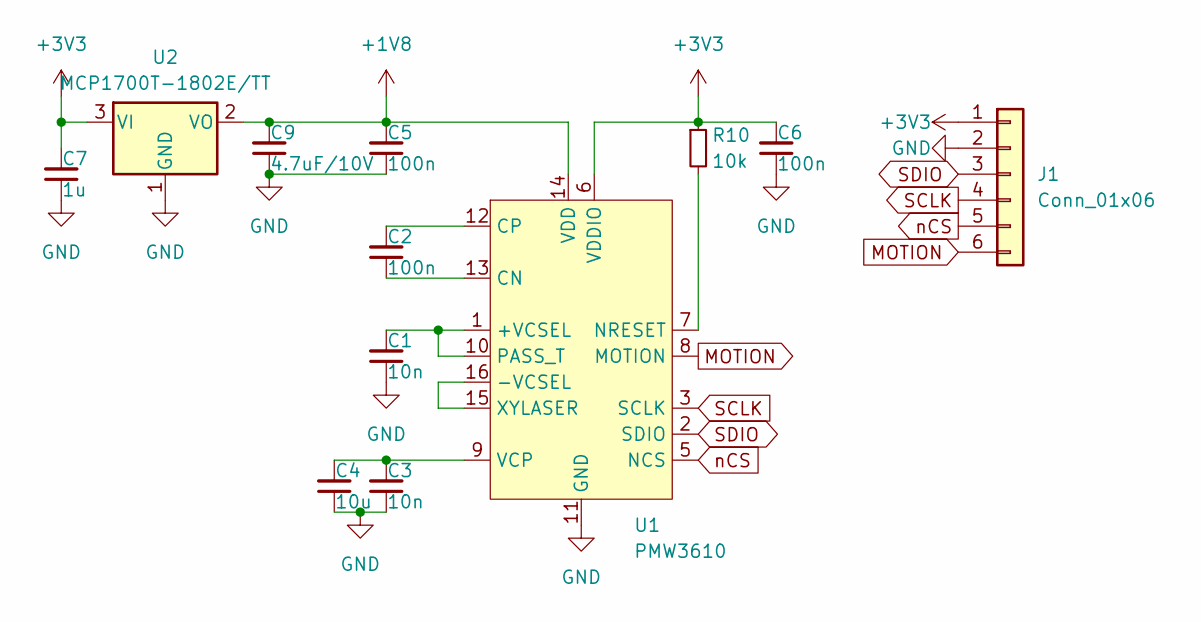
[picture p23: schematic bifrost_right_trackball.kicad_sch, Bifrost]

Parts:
C1, C3: 10n; C_0402_1005Metric; LCSC C15195
C2, C5, C6: 100n; C_0402_1005Metric; LCSC C1525
C4: 10u; C_0402_1005Metric; LCSC C15525
C7: 1u; C_0402_1005Metric; LCSC C52923
C9: 4.7uF/10V; C_0402_1005Metric; LCSC C23733
J1: Conn_01x06; PinHeader_1x06_P1.27mm_Vertical
R10: 10k; R_0402_1005Metric; LCSC C25744
U1: PMW3610; PMW3610DM-SUDU 16Pin; MFR. Part # PMW3610DM-SUDU; JLCPCB Part # C42442560
U2: MCP1700T-1802E/TT; SOT-23; LCSC C150796

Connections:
+1V8: C5.2, C9.2, U1.14 (VDD), U2.2 (VO)
+3V3: C6.2, C7.2, J1.1, R10.1, U1.6 (VDDIO), U2.3 (VI)
GND: C1.1, C3.1, C4.1, C5.1, C6.1, C7.1, C9.1, J1.2, U1.11 (GND), U2.1 (GND)
MOTION: J1.6, U1.8 (MOTION)
unnamed: C1.2, U1.1 (+VCSEL), U1.10 (PASS_T)
unnamed: U1.15 (XYLASER), U1.16 (-VCSEL)
unnamed: C2.1, U1.13 (CN)
unnamed: C2.2, U1.12 (CP)
unnamed: R10.2, U1.7 (NRESET)
unnamed: C3.2, C4.2, U1.9 (VCP)
SCLK: J1.4, U1.3 (SCLK)
SDIO: J1.3, U1.2 (SDIO)
nCS: J1.5, U1.5 (NCS)

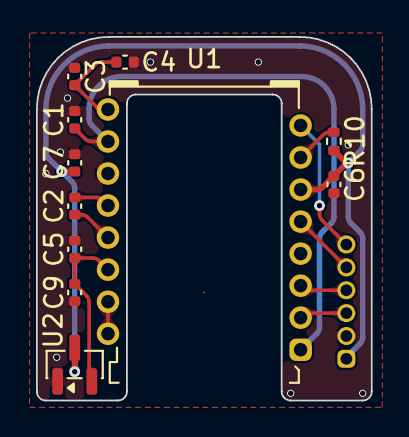
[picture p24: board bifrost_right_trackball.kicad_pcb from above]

Board: 2 copper layers, 18.6 x 20.2 mm, 12 parts (1 on the bottom side), 13 nets.

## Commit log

2026-08-04 Initial open hardware release
    [bifrost_left.kicad_pcb, bifrost_left.kicad_sch, bifrost_left_case.step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]
2026-08-06 Document case fabrication
2026-08-06 Clarify KiCad design status
2026-08-13 Update KiCad keyboard designs
    [bifrost_left.kicad_pcb, bifrost_left.kicad_sch, bifrost_left_plate.kicad_pcb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]
2026-08-13 Remove unused Smidr footprints
2026-08-13 Track PCB component 3D models
    [9774030243R.stp, Gateron Low Profile Socket.step, Gateron Low Profile Stabilizer 2U.step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]
2026-08-14 Use Old Norse Bifrǫst spelling
    [bifrost_left_thumb.kicad_sch, bifrost_right_thumb.kicad_sch]
2026-08-15 Update PCB designs
    [bifrost_left.kicad_pcb, bifrost_left.kicad_sch, bifrost_left_plate.kicad_pcb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]
2026-08-15 Document PCB fabrication requirements
    [bifrost_left_thumb.kicad_pcb, bifrost_left_thumb_plate.kicad_pcb, bifrost_right_thumb.kicad_pcb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]
2026-08-15 Update 3D models
    [bifrost_left_case.step, bifrost_left_plate.step, bifrost_left_thumb_plate.step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]
2026-08-15 Refine trackball PCB
    [bifrost_right_trackball.kicad_pcb]
2026-08-15 Exclude unverified PMW3610 model
    [PMW3610.step]
2026-08-15 Update trackball PCB and case
    [bifrost_right_case.step, bifrost_right_trackball.kicad_pcb, bifrost_trackball_case.step]
2026-08-16 docs: describe wireless controller
2026-08-16 Document battery and wire harness requirements
2026-08-16 Update PCB and case designs
    [bifrost_left.kicad_pcb, bifrost_left_case.step, bifrost_left_plate.kicad_pcb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]
2026-08-16 docs: describe power-switch knob
2026-08-16 Document maximum battery dimensions
2026-08-16 Update left and right case designs
    [bifrost_left_case.step, bifrost_right_case.step]
2026-08-16 Update PCB fabrication outputs and switch knob
    [bifrost_left.kicad_pcb, bifrost_left_thumb.kicad_pcb, bifrost_right.kicad_pcb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]
2026-08-16 Update main PCB BOMs and fabrication outputs
    [bifrost_left.kicad_pcb, bifrost_right.kicad_pcb, bom.csv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]
2026-08-16 Update PCB designs and fabrication outputs
    [bifrost_left.kicad_pcb, bifrost_left_thumb.kicad_pcb, bifrost_right.kicad_pcb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]
2026-08-16 Add product name silkscreen to PCBs
    [bifrost_left.kicad_pcb, bifrost_right.kicad_pcb]
2026-08-16 Update case and PCB production files
    [bifrost_left.kicad_pcb, bifrost_left_plate.step, bifrost_left_thumb_plate.step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]
2026-08-17 Update PCB layouts and production files
    [bifrost_left.kicad_pcb, bifrost_left_thumb.kicad_pcb, bifrost_right.kicad_pcb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]
2026-08-17 Update PCB BOM and manufacturing outputs
    [bifrost_left.kicad_pcb, bifrost_left.kicad_sch, bifrost_right.kicad_pcb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]
2026-08-17 Publish current main PCB manufacturing data
    [bifrost_left.kicad_pcb, bifrost_left.kicad_sch, bifrost_right.kicad_sch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]
2026-08-18 Refactor application implementation
    [bifrost_left.kicad_pcb, bifrost_left.kicad_sch, bifrost_right.kicad_pcb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]
2026-08-18 Update case and plate designs
    [bifrost_left_case.step, bifrost_left_plate.kicad_pcb, bifrost_left_plate.step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]
2026-08-21 Update Bifrost case and PCB outputs
    [bifrost_left.kicad_pcb, bifrost_left.kicad_sch, bifrost_left_case.step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]
2026-08-21 Update left case, right case, and PCB
    [bifrost_left.kicad_pcb, bifrost_left_case.step, bifrost_right_case.step]
2026-08-25 Remove local KiCad library paths
    [9774030243R.stp, SW_SMD_2P-TS24CA.step, SW_SPDT_Shouhan_MSK12C02.step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]
2026-08-28 Update PCB designs and production files
    [bifrost_left.kicad_pcb, bifrost_left.kicad_sch, bifrost_left_thumb.kicad_sch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]
2026-08-31 Refactor application structure and update implementation
    [BOM.xlsx, BOM_集計.xlsx, bifrost_left.kicad_pcb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]
2026-08-31 Update manufacturing spacer specifications
2026-09-04 Update PCB plate and stabilizer designs
    [bifrost_left.kicad_pcb, bifrost_left_plate.kicad_pcb, bifrost_left_plate.step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]
2026-09-07 Update PCB mounting hardware footprints
    [BOM_集計.xlsx, SMD-1_BD4.4-D2.8.step, bifrost_left.kicad_pcb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]
2026-09-11 Update PCB circuits and manufacturing data
    [bifrost_left.kicad_pcb, bifrost_left.kicad_sch, bifrost_right.kicad_pcb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]
2026-09-12 Update right PCB manufacturing data
    [bifrost_right.kicad_pcb, bom.csv, designators.csv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]
2026-09-20 Update trackball case and BOM
    [BOM_集計.xlsx, bifrost_trackball_case.step]
2026-10-11 Update case STEP models
